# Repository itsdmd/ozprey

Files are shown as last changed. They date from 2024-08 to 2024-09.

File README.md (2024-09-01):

# Ozprey - A remix of [osprey-remix](https://github.com/kapee1/osprey-remix)

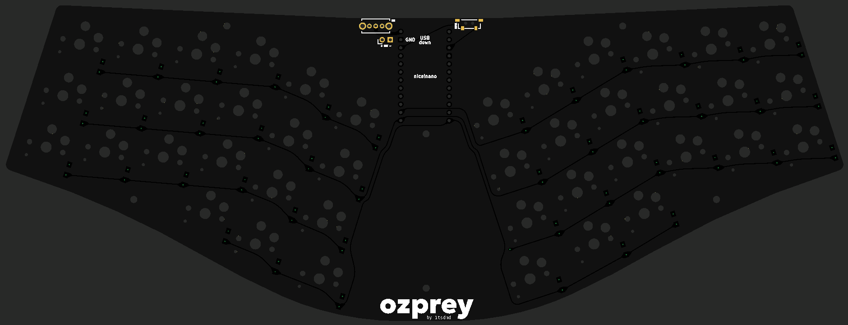
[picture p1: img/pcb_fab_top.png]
Ozprey PCB Top - JLCPCB render

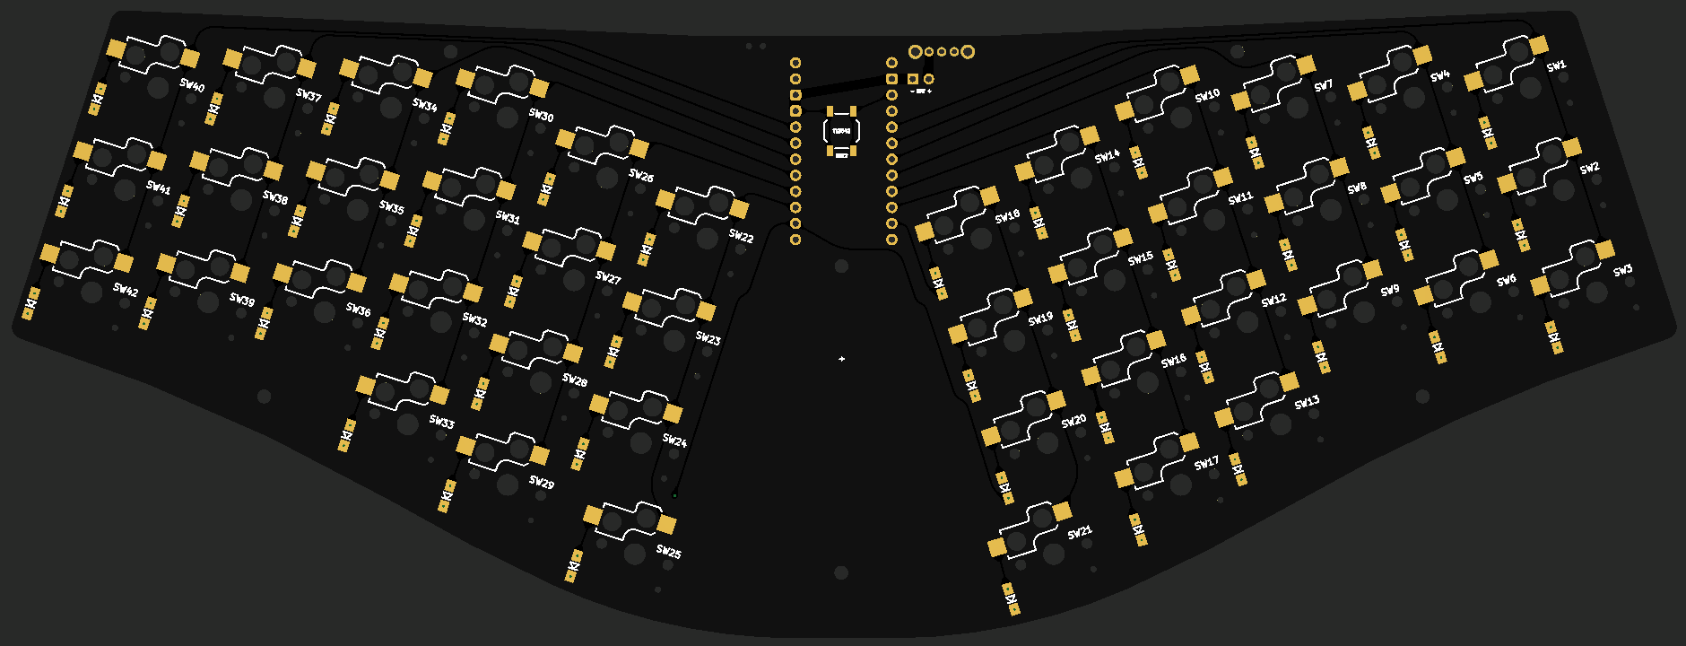
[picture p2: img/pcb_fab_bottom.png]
Ozprey PCB Bottom - JLCPCB render

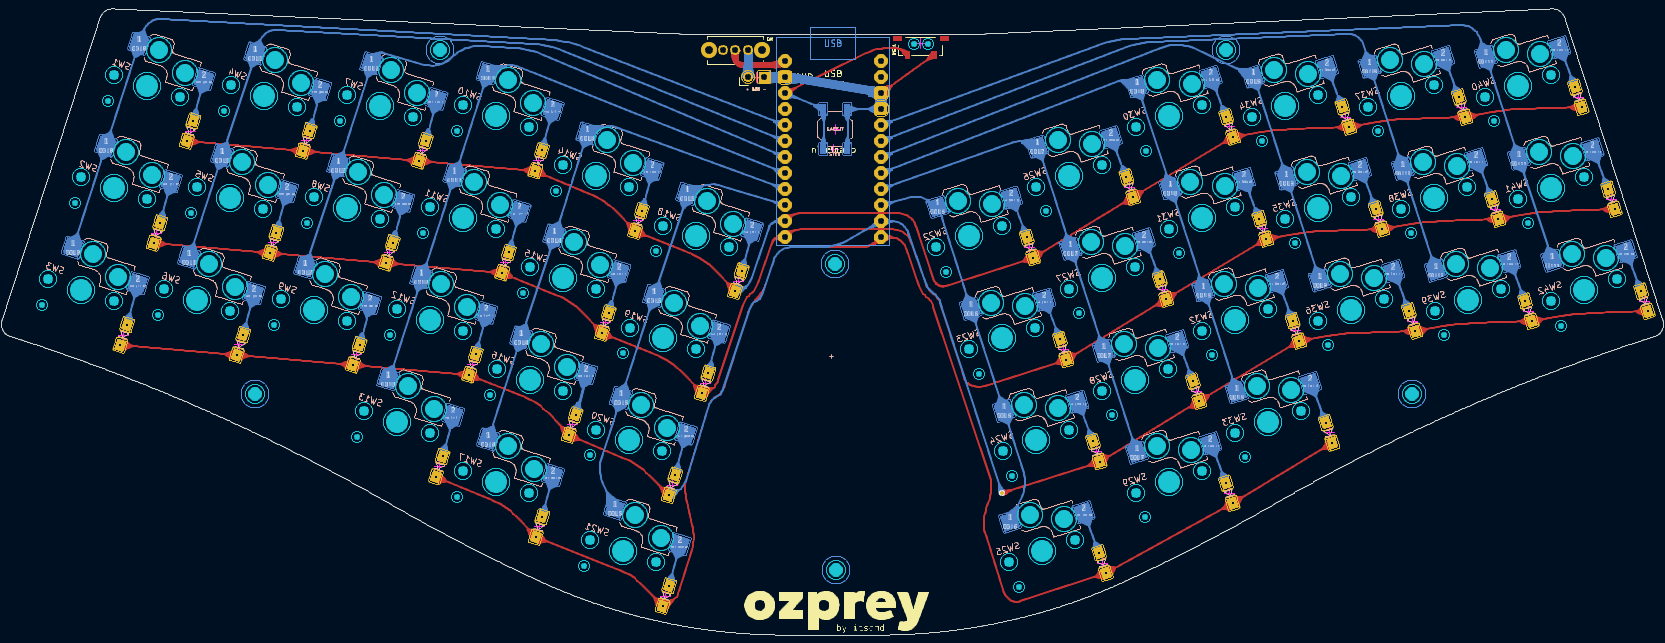
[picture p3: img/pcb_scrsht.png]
Ozprey PCB - KiCad render


## Changes compared to the original Osprey

-   Remove cutout under MCU to allow more flexible PCB trace routing.
-   Remove battery holder cutout, replace onboard battery connector socket with battery connector pads.
    -   These changes were made since I want to use a large Li-Po battery placed under the PCB.
-   Simplify top edge, widen the split gap to accomodate changed switch footprint.
-   Replace power and reset switch footprint. Schematics for both can be found inside [img](./img) folder.
-   Adjust onboard M2 mounting holes' position.

These changes made the board incompatible with the original case & plate. You can get the [.STEP file](./ozprey_case/osprey_pcb.step) and design your own case & plate.

## Thanks

Huge thanks to [ebastler](https://github.com/ebastler), author of the [original project](https://github.com/ebastler/osprey) for the inspiration and design, and [kapee1](https://github.com/kapee1) for the nice!nano implementation with the [osprey-remix](https://github.com/kapee1/osprey-remix).

The keyboard switch footprint was from [daprice/keyswitches.pretty](https://github.com/daprice/keyswitches.pretty).

## Disclaimer

This is a **personal project** and not affiliated with the original authors. Due to the changes, the board is not compatible with the original case and plate.

The gerber file has been checked against JLCPCB's DFM checker and no critical error was found. All files are provided as-is, **without any warranty or support**. Use at your own risk.

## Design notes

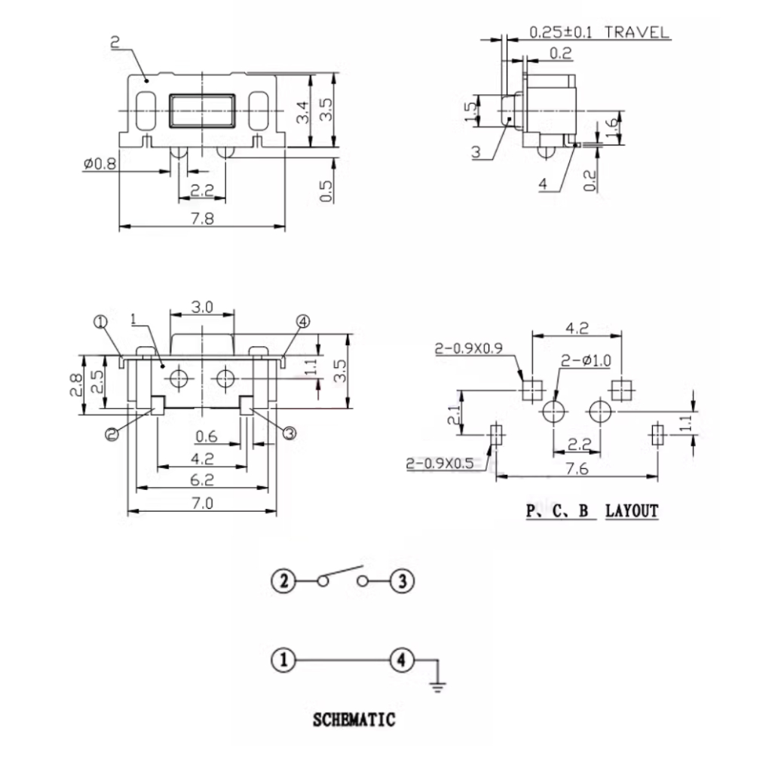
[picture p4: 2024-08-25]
img/sw_reset_schematic.jpg

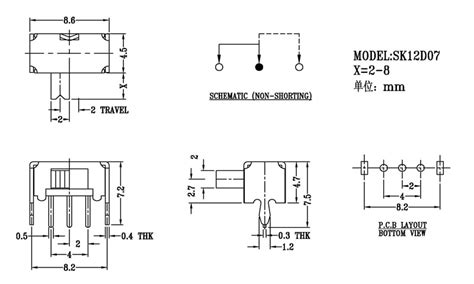
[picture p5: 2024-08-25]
img/sw_sk12d07_schematic.jpg

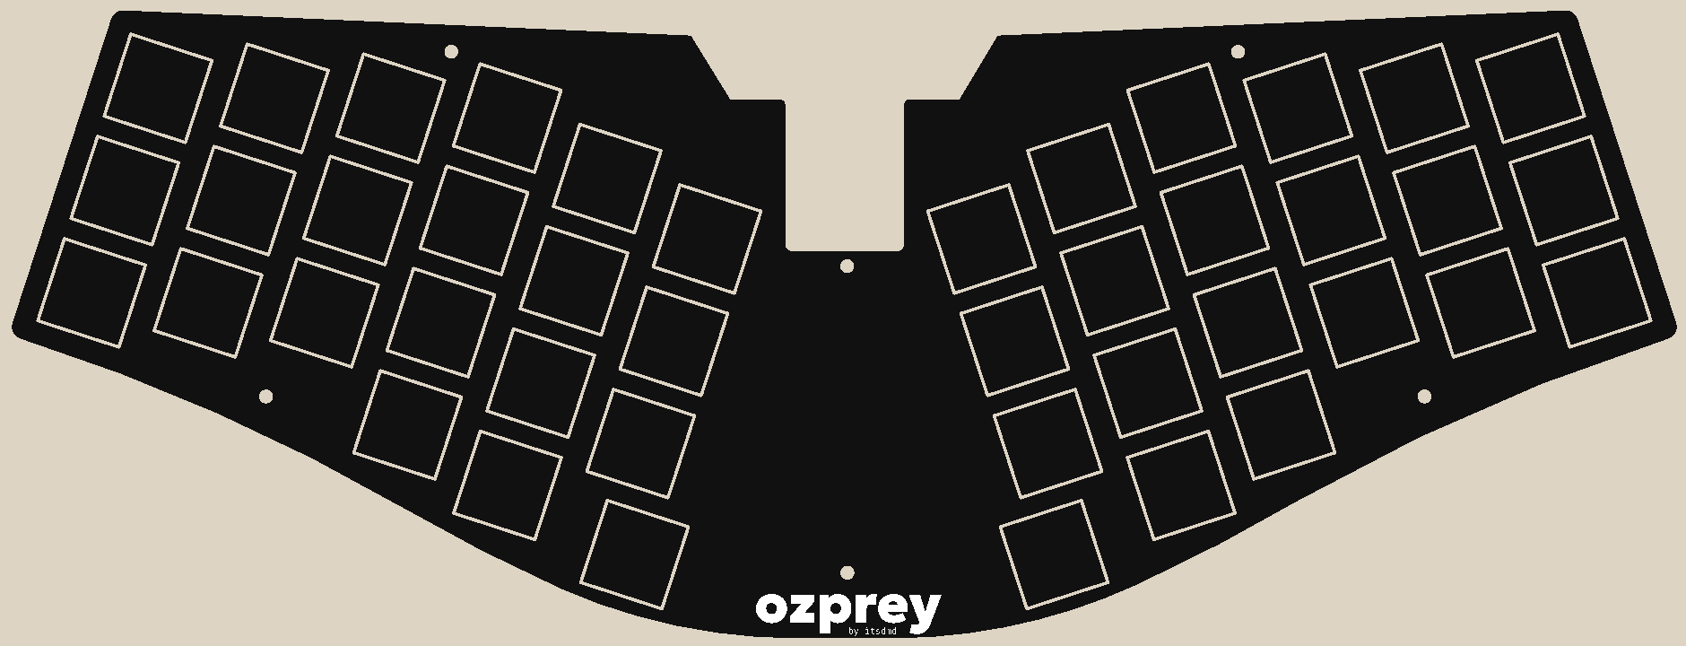
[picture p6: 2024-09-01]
img/plate_fab.png

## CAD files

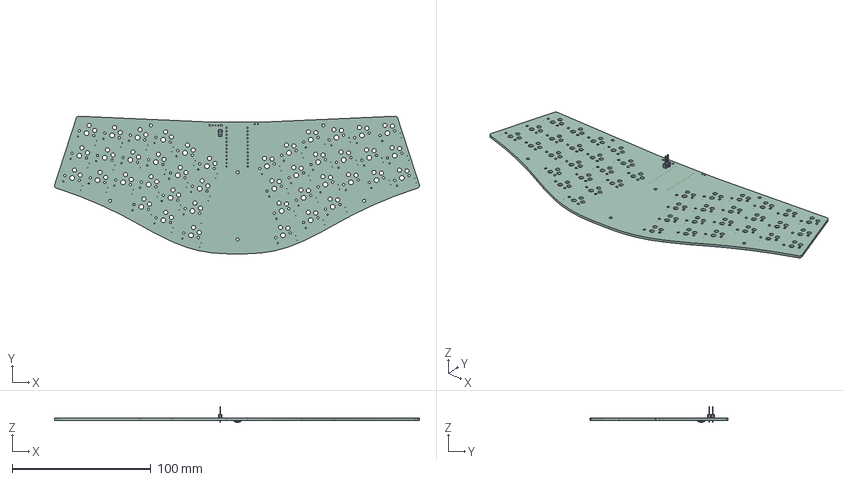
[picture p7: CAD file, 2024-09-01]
ozprey_case/osprey_pcb.step
263.5 x 99.3 x 11.8 mm
PinHeader_1x02_P254mm_Vertical
SW_SPST_TL3342
ozprey_PCB

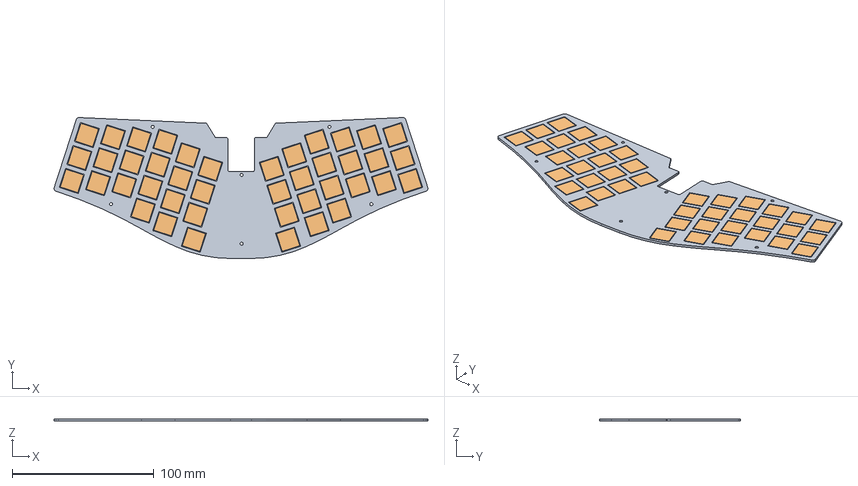
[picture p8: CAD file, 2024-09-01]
ozprey_case/osprey_plate.step
263.5 x 99.3 x 1.60 mm

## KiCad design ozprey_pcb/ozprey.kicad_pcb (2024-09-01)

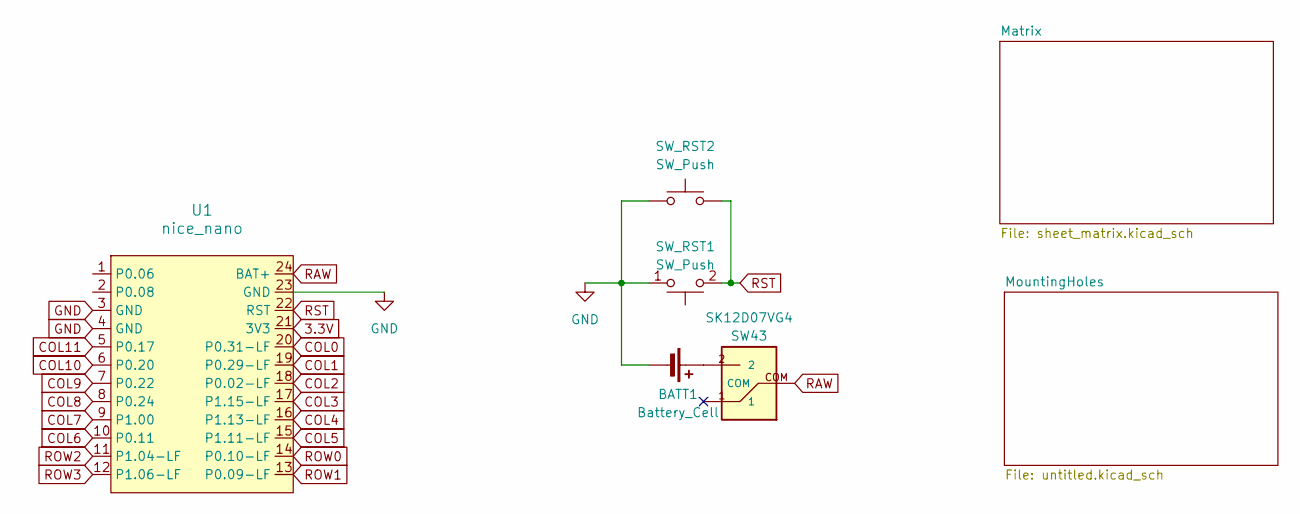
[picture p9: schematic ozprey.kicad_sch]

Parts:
BATT1: Battery_Cell; Battery_Pads-dual-side
SW43: SK12D07VG4; SW-S_SK12D07VG4
SW_RST1: SW_Push; SW-S_7.4x2.6-4pad-smd
SW_RST2: SW_Push; SW-T_SPST_TL3342
U1: nice_nano; MCB_nice-nano_flip

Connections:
3.3V: U1.21 (3V3)
COL0: U1.20 (P0.31-LF); also elsewhere on the board
COL1: U1.19 (P0.29-LF); also elsewhere on the board
COL2: U1.18 (P0.02-LF); also elsewhere on the board
COL3: U1.17 (P1.15-LF); also elsewhere on the board
COL4: U1.16 (P1.13-LF); also elsewhere on the board
COL5: U1.15 (P1.11-LF); also elsewhere on the board
COL6: U1.10 (P0.11); also elsewhere on the board
COL7: U1.9 (P1.00); also elsewhere on the board
COL8: U1.8 (P0.24); also elsewhere on the board
COL9: U1.7 (P0.22); also elsewhere on the board
COL10: U1.6 (P0.20); also elsewhere on the board
COL11: U1.5 (P0.17); also elsewhere on the board
GND: BATT1.2 (-), SW_RST1.1, SW_RST2.1, U1.3 (GND), U1.4 (GND), U1.23 (GND); also elsewhere on the board
unnamed: BATT1.1 (+), SW43.2
RAW: SW43.COM, U1.24 (BAT+)
ROW0: U1.14 (P0.10-LF); also elsewhere on the board
ROW1: U1.13 (P0.09-LF); also elsewhere on the board
ROW2: U1.11 (P1.04-LF); also elsewhere on the board
ROW3: U1.12 (P1.06-LF); also elsewhere on the board
RST: SW_RST1.2, SW_RST2.2, U1.22 (RST); also elsewhere on the board

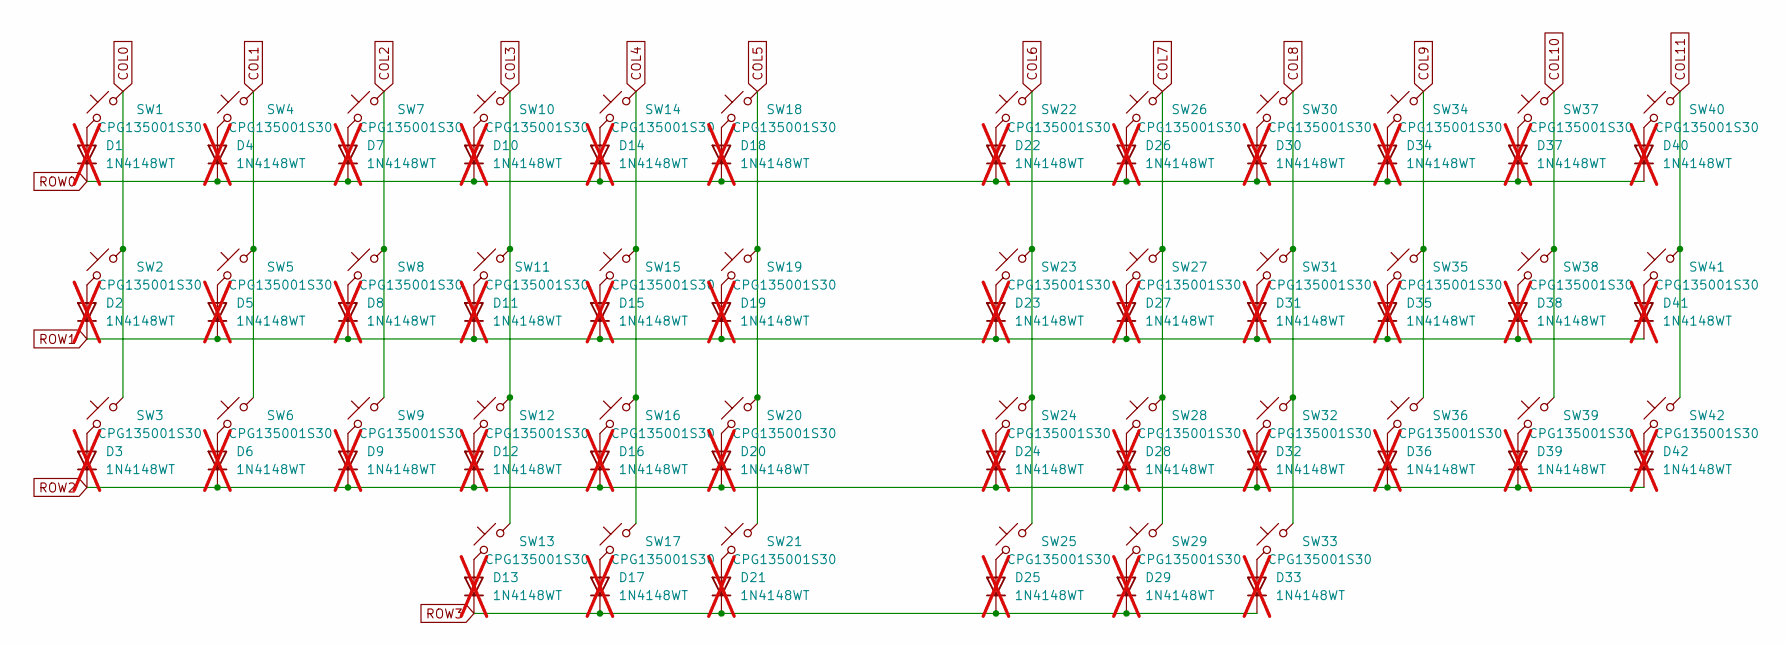
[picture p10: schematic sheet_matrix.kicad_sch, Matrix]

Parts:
D1, D2, D3, D4, D5, D6, D7, D8, D9, D10, D11, D12, D13, D14, D15, D16, D17, D18, D19, D20, D21, D22, D23, D24, D25, D26, D27, D28, D29, D30, D31, D32, D33, D34, D35, D36, D37, D38, D39, D40, D41, D42: 1N4148WT; D_SOD-123; not fitted
SW1, SW2, SW3, SW4, SW5, SW6, SW7, SW8, SW9, SW10, SW11, SW12, SW13, SW14, SW15, SW16, SW17, SW18, SW19, SW20, SW21, SW22, SW23, SW24, SW25, SW26, SW27, SW28, SW29, SW30, SW31, SW32, SW33, SW34, SW35, SW36, SW37, SW38, SW39, SW40, SW41, SW42: CPG135001S30; KS_Socket_Choc

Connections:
COL0: SW1.1, SW2.1, SW3.1; also elsewhere on the board
COL1: SW4.1, SW5.1, SW6.1; also elsewhere on the board
COL2: SW7.1, SW8.1, SW9.1; also elsewhere on the board
COL3: SW10.1, SW11.1, SW12.1, SW13.1; also elsewhere on the board
COL4: SW14.1, SW15.1, SW16.1, SW17.1; also elsewhere on the board
COL5: SW18.1, SW19.1, SW20.1, SW21.1; also elsewhere on the board
COL6: SW22.1, SW23.1, SW24.1, SW25.1; also elsewhere on the board
COL7: SW26.1, SW27.1, SW28.1, SW29.1; also elsewhere on the board
COL8: SW30.1, SW31.1, SW32.1, SW33.1; also elsewhere on the board
COL9: SW34.1, SW35.1, SW36.1; also elsewhere on the board
COL10: SW37.1, SW38.1, SW39.1; also elsewhere on the board
COL11: SW40.1, SW41.1, SW42.1; also elsewhere on the board
unnamed: D1.2 (A), SW1.2
unnamed: D2.2 (A), SW2.2
unnamed: D3.2 (A), SW3.2
unnamed: D4.2 (A), SW4.2
unnamed: D5.2 (A), SW5.2
unnamed: D6.2 (A), SW6.2
unnamed: D7.2 (A), SW7.2
unnamed: D8.2 (A), SW8.2
unnamed: D9.2 (A), SW9.2
unnamed: D10.2 (A), SW10.2
unnamed: D11.2 (A), SW11.2
unnamed: D12.2 (A), SW12.2
unnamed: D13.2 (A), SW13.2
unnamed: D14.2 (A), SW14.2
unnamed: D15.2 (A), SW15.2
unnamed: D16.2 (A), SW16.2
unnamed: D17.2 (A), SW17.2
unnamed: D18.2 (A), SW18.2
unnamed: D19.2 (A), SW19.2
unnamed: D20.2 (A), SW20.2
unnamed: D21.2 (A), SW21.2
unnamed: D22.2 (A), SW22.2
unnamed: D23.2 (A), SW23.2
unnamed: D24.2 (A), SW24.2
unnamed: D25.2 (A), SW25.2
unnamed: D26.2 (A), SW26.2
unnamed: D27.2 (A), SW27.2
unnamed: D28.2 (A), SW28.2
unnamed: D29.2 (A), SW29.2
unnamed: D30.2 (A), SW30.2
unnamed: D31.2 (A), SW31.2
unnamed: D32.2 (A), SW32.2
unnamed: D33.2 (A), SW33.2
unnamed: D34.2 (A), SW34.2
unnamed: D35.2 (A), SW35.2
unnamed: D36.2 (A), SW36.2
unnamed: D37.2 (A), SW37.2
unnamed: D38.2 (A), SW38.2
unnamed: D39.2 (A), SW39.2
unnamed: D40.2 (A), SW40.2
unnamed: D41.2 (A), SW41.2
unnamed: D42.2 (A), SW42.2
ROW0: D1.1 (K), D4.1 (K), D7.1 (K), D10.1 (K), D14.1 (K), D18.1 (K), D22.1 (K), D26.1 (K), D30.1 (K), D34.1 (K), D37.1 (K), D40.1 (K); also elsewhere on the board
ROW1: D2.1 (K), D5.1 (K), D8.1 (K), D11.1 (K), D15.1 (K), D19.1 (K), D23.1 (K), D27.1 (K), D31.1 (K), D35.1 (K), D38.1 (K), D41.1 (K); also elsewhere on the board
ROW2: D3.1 (K), D6.1 (K), D9.1 (K), D12.1 (K), D16.1 (K), D20.1 (K), D24.1 (K), D28.1 (K), D32.1 (K), D36.1 (K), D39.1 (K), D42.1 (K); also elsewhere on the board
ROW3: D13.1 (K), D17.1 (K), D21.1 (K), D25.1 (K), D29.1 (K), D33.1 (K); also elsewhere on the board

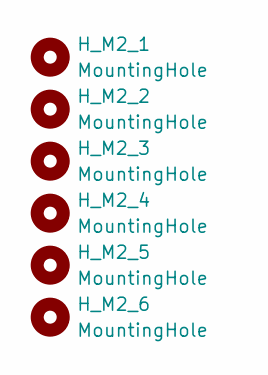
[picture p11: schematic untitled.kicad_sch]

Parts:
H_M2_1, H_M2_2, H_M2_3, H_M2_4, H_M2_5, H_M2_6: MountingHole; MountingHole_2.2mm_M2

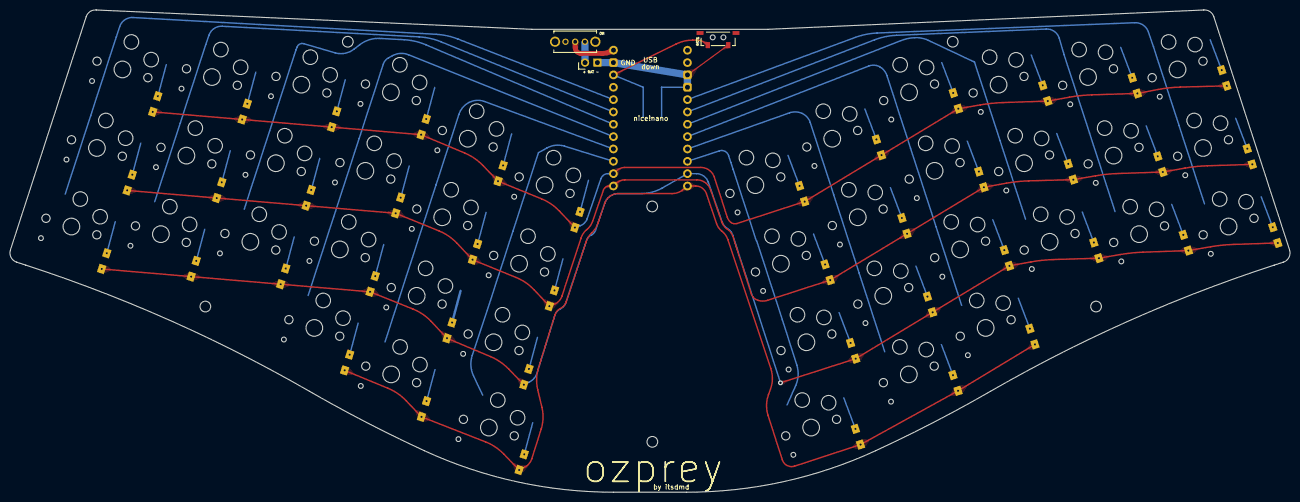
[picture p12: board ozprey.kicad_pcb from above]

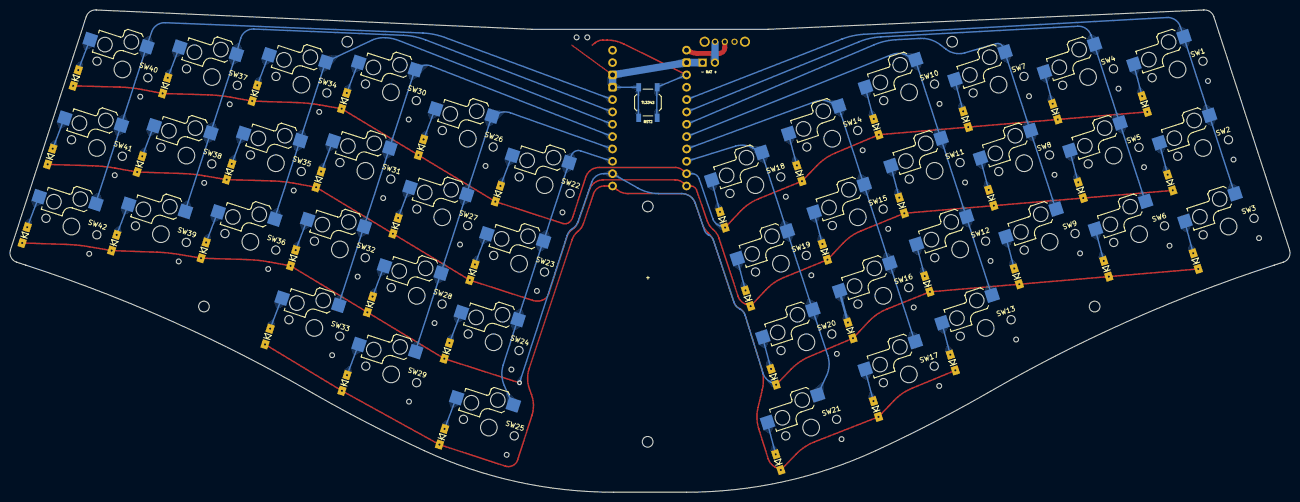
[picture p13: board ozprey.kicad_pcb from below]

Board: 2 copper layers, 263.5 x 99.3 mm, 95 parts (43 on the bottom side), 62 nets.

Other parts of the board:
RST2: SW_Push; SW-T_SPST_TL3342

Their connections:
GND: RST2.1; also elsewhere on the board
RST: RST2.2; also elsewhere on the board

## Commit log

2024-08-25 rework pcb, remove enclosure & plate folders
    [ozprey-B_Cu.gbl, ozprey-B_Mask.gbs, ozprey-B_Paste.gbp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]
2024-08-25 update doc
    [ozprey.kicad_pcb, ozprey.kicad_sch, untitled.kicad_sch]
2024-08-25 add gerber
    [ozprey-B_Cu.gbl, ozprey-B_Mask.gbs, ozprey-B_Paste.gbp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]
2024-08-25 update m2 holes pos
    [ozprey-B_Cu.gbl, ozprey-B_Mask.gbs, ozprey-B_Paste.gbp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]
2024-08-25 replace power & reset switches
    [osprey_pcb.step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]
2024-09-01 major changes, add plate
    [osprey_pcb.step, osprey_plate.step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]
2024-09-01 add plate image
